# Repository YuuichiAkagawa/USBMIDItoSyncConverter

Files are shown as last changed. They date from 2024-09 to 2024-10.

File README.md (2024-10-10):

# USB MIDI to Sync Converter
Converts USB MIDI clock messages to sync signals.

[日本語版](README-ja.md)

## How to build
### Target microcontroller
- Seeed XIAO RP2040

### Build
This project uses Arduino IDE2 and requires the following libraries:
- board: [Arduino-pico](https://github.com/earlephilhower/arduino-pico) 4.1.1
- library: [Arduino MIDI Library](https://github.com/FortySevenEffects/arduino_midi_library) 5.0.2

Build setting:
- Tools->Board:->Raspberry Pi Pico/RP2040->Seed XIAO RP2040
- Tools->USB Stack:->Adafruilt TinyUSB

## Schematic
Complete schematic created in [KiCad](./hardware/KiCad/USBMIDItoSYNC_Converter/).

Minimum configuration with sync signal output terminal only
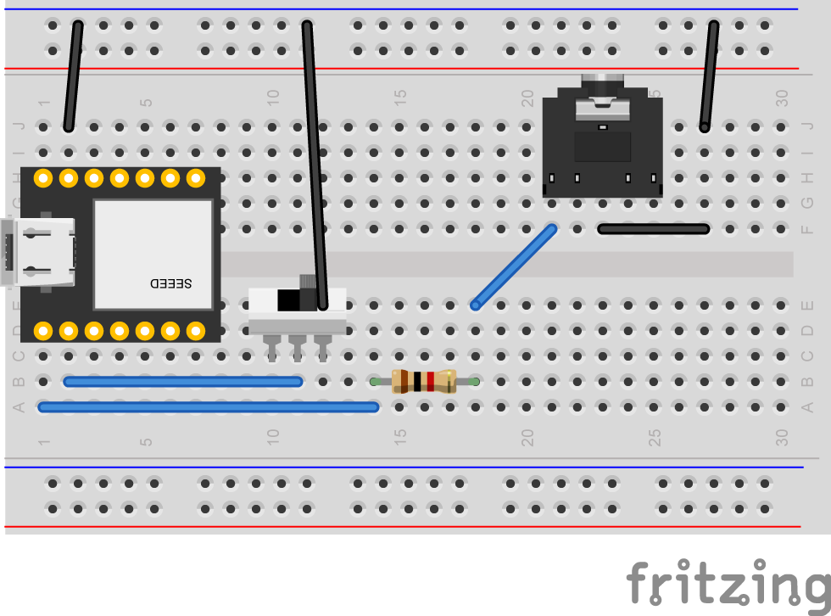
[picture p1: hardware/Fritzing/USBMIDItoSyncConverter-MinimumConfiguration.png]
Fritzing


## Usage
Connects to the sending MIDI device with a USB cable and to the receiving device with a 3.5 mm stereo cable.  
The run mode switch can be used to select the action to be taken when a MIDI START/STOP message is received.

### Run mode switch
The D1 pin is assigned to mode switch. D1 is pulled up and goes High when open.

|D1 |behaviour|
|----|---|
|Low |Sends out or stops the sync signal in conjunction with MIDI Start and Stop messages.|
|High|Free run. When MIDI Clock is received, the Sync signal is sent regardless of the playback status of the MIDI device.|

### DIN SYNC (experimental)
The DIN SYNC Start/Stop signal is output to the D2 pin.
D2 pin is assigned to 'DIN S' on the DIP switch and is connected to the RING of the Sync terminal.

### TRS MIDI In/Out (TypeA)
Transfers MIDI messages between USB MIDI and TRS MIDI.  
Note:
- SysEx is not supported.
- The clock input from TRS MIDI IN cannot be converted to a Sync signal.
  
### Setting switch
The setting switches can be used to set PPQ values and MIDI filter settings.  

|pin|name | setting |
|---|-----|---|
|D5 |MODE0|Type setting<br>L:PPQ values are changed using Setting switch. The value stored in the EEPROM is ignored.<br>H:PPQ values are changed using SysEx messages. Settings are saved in EEPROM.
|D4 |MODE1|MODE0=L : PPQ selecter<br>MODE0=H : MIDI FilterSelector
|D3 |MODE2|MODE0=L : PPQ selecter<br>MODE0=H : MIDI FilterSelector

#### MODE0=0 PPQ selector
|MODE1 |MODE2 | PPQ |
|---|---|---|
|H(Off)|H(Off)|1 |
|H(Off)|L(On) |2 |
|L(On) |H(Off)|4 |
|L(On) |L(On) |24 |

#### MODE0=1 MIDI Filter
|MODE1 |MODE2 | Filter |
|---|---|---|
|H(Off)|H(Off)|All messages are forwarded from USB to TRS MIDI Out |
|H(Off)|L(On) |Only Clock, Start, Stop, Continue are fowarded. |
|L(On) |H(Off)|Foward only clocks |
|L(On) |L(On) |N/A (Reserved) |

## About the pulse width of the sync signal
In this project, the pulse width of the sync signal is set to 5 ms.  
The reason for this is that the KORG specification is 15 ms, but many other companies' devices use 5 ms.  
If you want to change this, modify the definition of ```DEFAULT_SPW``` to ```SPW_15MS``` and rebuild.

## Change the PPQ via SysEx message
The PPQ values can be changed using SysEx messages.  
You can specify a value between 1 and 24, but it will not work correctly unless it is a divisor of 24.  
The PPQ value is stored in the EEPROM at location 0x00.

|Byte[Hex] | Description |
|:---:|---|
|F0 | Exclusive Status |
|7E | non realtime Universal System Exclusive Message |
|49 | Device ID |
|0B | File Reference Message |
|02 | Change (Select or Reselect) |
|nn | PPQ : 1,2,3,4,6,8,0Ch(12),18h(24) |
|F7 | End Of Exclusive |

## Change the Sync signal pulse width via SysEx message
The Sync signal pulse width can be changed using a SysEx message.  
It can be set to 5ms or 15ms.  
The Sync signal pulse width value is stored in the EEPROM at location 0x01.

|Byte[Hex] | Description |
|:---:|---|
|F0 | Exclusive Status |
|7E | non realtime Universal System Exclusive Message |
|49 | Device ID |
|0B | File Reference Message |
|02 | Change (Select or Reselect) |
|nn | Pulse Width 5ms:3Fh(63), 15ms:5Fh(95), Reserved:7Fh(127)|
|F7 | End Of Exclusive |

SysEx files are stored in assets/sysex. Use as needed.

Note: The SysEx message does not define a dedicated one, but rather diverts the universal system-exclusive File Reference Message.

## License
USB MIDI to Sync Converter is open source and licensed under the [GPL3](/LICENSE) License.

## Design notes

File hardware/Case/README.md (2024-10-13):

# Case
You can print the case on your 3D printer.  
The model for this case was created in FreeCAD.

## BOM
- Insert nut : M2 x 3mm L x 4mm
- Screw : M2x6

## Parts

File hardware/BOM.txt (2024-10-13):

 # |  package |  parts    |
---+----------+-----------+--------------------------------------------------
U1 |          |XIAO RP2040|Seeed XIAO RP2040 board
U2 |SO6       |TLP2368    |Photo coupler (open collector output)
U3 |SOT3-5    |SN74LV1T34 |Single Power Supply BUFFER Logic Level Shifter
R1 |1608(0603)|220Ω      |Register
R2 |1608(0603)|220Ω      |Register
R3 |1608(0603)|220Ω      |Register
R4 |1608(0603)|1kΩ       |Register
R5 |1608(0603)|1kΩ       |Register
R6 |1608(0603)|1kΩ       |Register
C1 |1608(0603)|0.1uF      |Ceramic capacitor
D1 |SOD123    |1N4148W    |Switching Diode
D2 |SOD523    |BAT43XV2   |Shotkey Diode 30V200mA
D3 |SOD523    |BAT43XV2   |Shotkey Diode 30V200mA
D4 |SOD523    |BAT43XV2   |Shotkey Diode 30V200mA
D5 |SOD523    |BAT43XV2   |Shotkey Diode 30V200mA
J1 |          |MJ8435     |3.5mm Stereo mini jack
J2 |          |MJ8435     |3.5mm Stereo mini jack
J3 |          |MJ8435     |3.5mm Stereo mini jack
SW1|          |3P SW      |Slide Switch 1P2T Right Angle
SW2|SO8       |KHS42E     |DIP Switch 4P SMT
---+----------+-----------+--------------------------------------------------

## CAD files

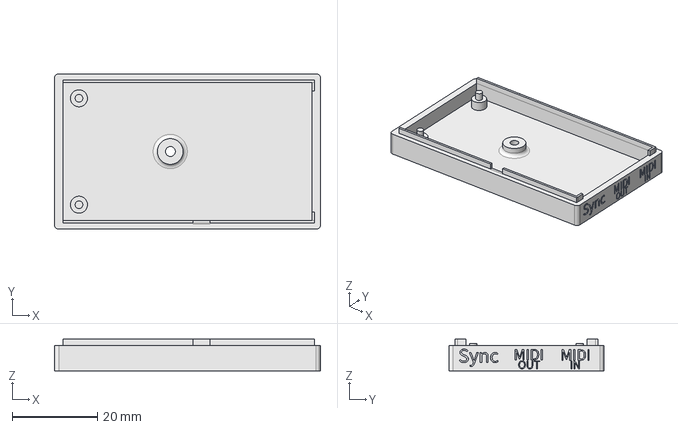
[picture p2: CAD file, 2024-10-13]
hardware/Case/UM2S-case-bottom.FCStd
62.5 x 36.5 x 7.50 mm

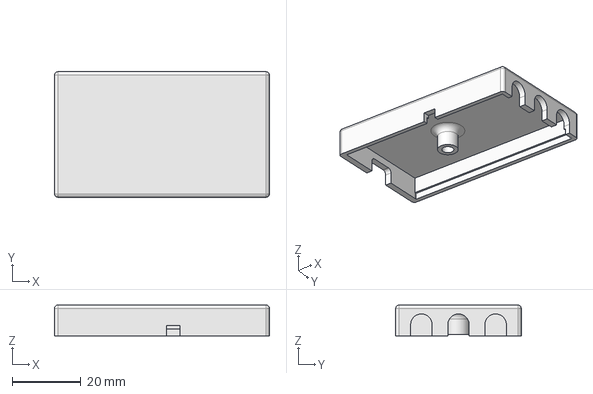
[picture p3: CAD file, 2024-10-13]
hardware/Case/UM2S-case-top.FCStd
62.5 x 36.5 x 9.00 mm

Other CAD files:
hardware/Case/UM2S-case-bottom.stl
hardware/Case/UM2S-case-top.stl

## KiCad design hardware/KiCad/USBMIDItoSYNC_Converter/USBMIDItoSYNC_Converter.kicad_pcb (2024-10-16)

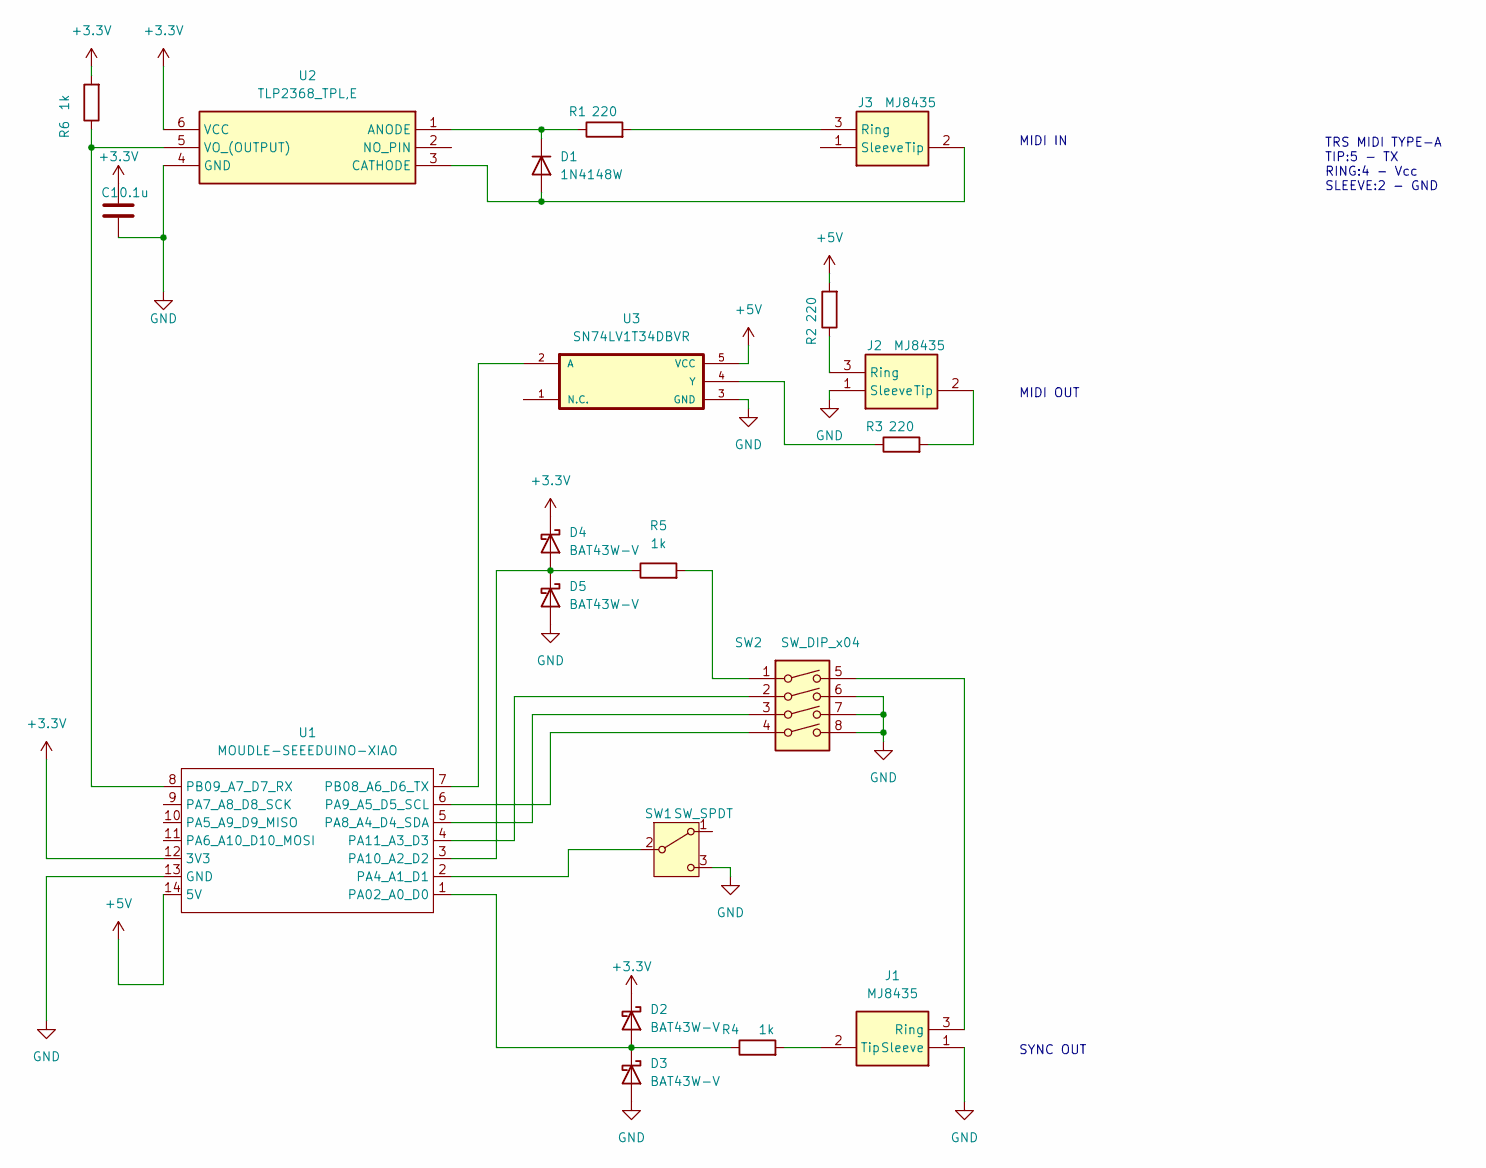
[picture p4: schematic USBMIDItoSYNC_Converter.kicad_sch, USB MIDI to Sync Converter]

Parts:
C1: 0.1u; C_0603_1608Metric
D1: 1N4148W; D_SOD-123
D2, D3, D4, D5: BAT43W-V; D_SOD-523
J1, J2, J3: MJ8435; Manufacturer_Part_Number MJ8435
R1, R2, R3: 220; R_0603_1608Metric
R4, R5, R6: 1k; R_0603_1608Metric
SW1: SW_SPDT; PinHeader_1x03_P2.54mm_Vertical
SW2: SW_DIP_x04; KHS42E
U1: MOUDLE-SEEEDUINO-XIAO; MOUDLE14P-XIAO-SMD-2.54-21X17.8MM
U2: TLP2368_TPL,E; SOIC127P700X230-6N; Manufacturer_Part_Number TLP2368(TPL,E; Mouser Part Number 757-TLP2368TPLE
U3: SN74LV1T34DBVR; SOT95P280X145-5N

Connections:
+3.3V: C1.1, D2.1 (K), D4.1 (K), R6.2, U1.12 (3V3), U2.6 (VCC)
+5V: R2.2, U1.14 (5V), U3.5 (VCC)
GND: C1.2, D3.2 (A), D5.2 (A), J1.1 (Sleeve), J2.1 (Sleeve), SW1.3 (C), SW2.6, SW2.7, SW2.8, U1.13 (GND), U2.4 (GND), U3.3 (GND)
unnamed: D1.2 (A), J3.2 (Tip), U2.3 (CATHODE)
unnamed: D1.1 (K), R1.1, U2.1 (ANODE)
unnamed: D2.2 (A), D3.1 (K), R4.1, U1.1 (PA02_A0_D0)
unnamed: D4.2 (A), D5.1 (K), R5.1, U1.3 (PA10_A2_D2)
unnamed: J1.3 (Ring), SW2.5
unnamed: J1.2 (Tip), R4.2
unnamed: J2.3 (Ring), R2.1
unnamed: J2.2 (Tip), R3.2
unnamed: J3.3 (Ring), R1.2
unnamed: R5.2, SW2.1
unnamed: SW1.2 (B), U1.2 (PA4_A1_D1)
unnamed: SW2.3, U1.5 (PA8_A4_D4_SDA)
unnamed: SW2.4, U1.6 (PA9_A5_D5_SCL)
unnamed: SW2.2, U1.4 (PA11_A3_D3)
unnamed: U1.7 (PB08_A6_D6_TX), U3.2 (A)
unnamed: R6.1, U1.8 (PB09_A7_D7_RX), U2.5 (VO_(OUTPUT))
unnamed: R3.1, U3.4 (Y)

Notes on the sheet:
MIDI IN
TRS MIDI TYPE-A TIP:5 - TX RING:4 - Vcc SLEEVE:2 - GND
SYNC OUT
MIDI OUT

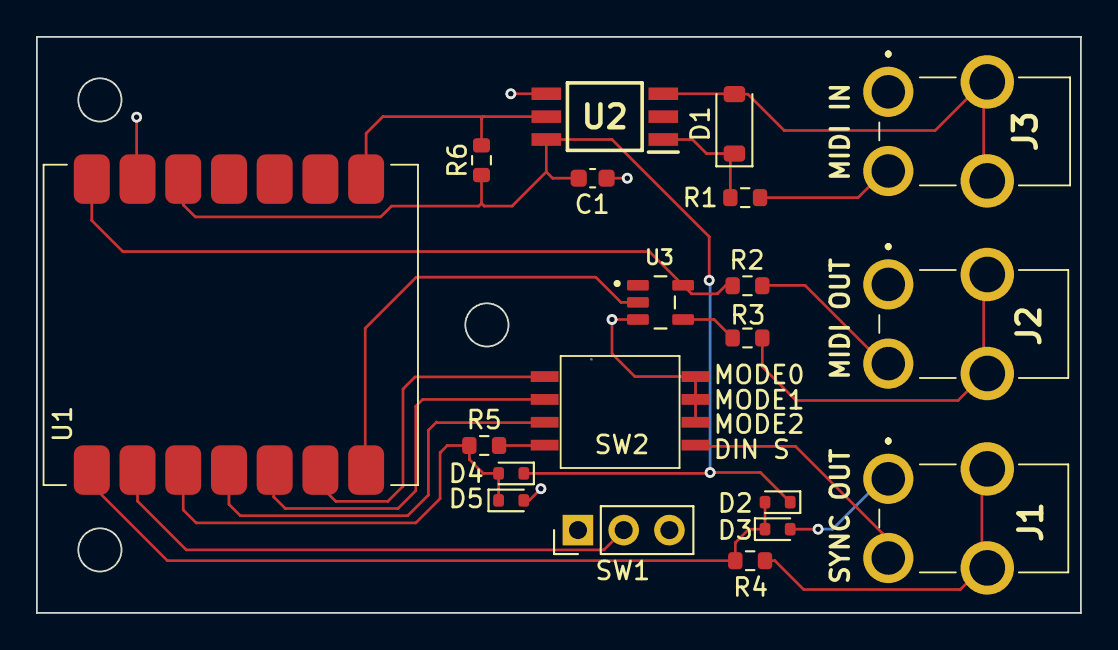
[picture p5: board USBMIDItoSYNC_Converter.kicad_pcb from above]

Board: 2 copper layers, 58.0 x 32.0 mm, 20 parts (0 on the bottom side), 20 nets.

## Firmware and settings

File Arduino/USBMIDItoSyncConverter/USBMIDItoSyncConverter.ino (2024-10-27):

/*
 * USB MIDI to Sync Converter for XIAO RP2040
 * Copyright (C) 2024 Yuuichi Akagawa
 *
 * This program is free software: you can redistribute it and/or modify it under the terms of 
 * the GNU General Public License as published by the Free Software Foundation, either version 3 
 * of the License, or any later version.
 * This program is distributed in the hope that it will be useful, but WITHOUT ANY WARRANTY; 
 * without even the implied warranty of MERCHANTABILITY or FITNESS FOR A PARTICULAR PURPOSE. 
 * See the GNU General Public License for more details.
 * You should have received a copy of the GNU General Public License along with this program. 
 * If not, see <https://www.gnu.org/licenses/>. 
 *
*/

#include <Arduino.h>
#include <Adafruit_TinyUSB.h>
#include <MIDI.h>
#include <EEPROM.h>

#define DEBUG
/* On-board LED definitions */
#define USER_LED_R 17  //RX_LED
#define USER_LED_G 16  //TX_LED
#define USER_LED_B 25

/* Pin definitions */
#define SYNCPIN D0
#define MODEPIN D1
#define DINSYNCRUNPIN D2
#define MODE0PIN D5
#define MODE1PIN D4
#define MODE2PIN D3
#define MODE0BIT 2
#define MODE1BIT 1
#define MODE2BIT 0

/* PPQ (default: 2PPQ)*/
#define CLOCK_BASE (24)
#define DEFAULT_PPQN (2)

/* Sync Pulse Width (SPW) */
#define SPW_5MS (1)
#define SPW_15MS (2)
#define SPW_RESERVED (3)
#define DEFAULT_SPW SPW_5MS

/* EEPROM address*/
#define EEPROM_ADDRESS_PPQN 0x00
#define EEPROM_ADDRESS_SPW 0x01

/* MIDI filter */
#define MIDI_FILTER_NONE (3)
#define MIDI_FILTER_TRANSPORT (2)
#define MIDI_FILTER_CLOCKONLY (1)

/* MIDI device ID for SysEx */
#define SYSEX_DEVICE_ID (0x49)

//Global valiables
uint32_t g_ppqn = DEFAULT_PPQN;  // current PPQN
uint32_t g_clock_period;         // Period of the MIDI Clock that fires the Sync signal
int32_t g_spw = -5;              // current Sync pluse width
uint32_t g_count_clock = 0;      // Number of MIDI Clocks received
bool g_is_start = false;         // Is MIDI Start received
uint32_t g_midi_filter = MIDI_FILTER_NONE;
uint32_t g_dipsw_mode_value = 0;

//timer
static repeating_timer_t timer;

// USB MIDI object
Adafruit_USBD_MIDI usb_midi;

// Create a new instance of the Arduino MIDI Library, and attach usb_midi as the transport.
MIDI_CREATE_INSTANCE(Adafruit_USBD_MIDI, usb_midi, USBMIDI);
// Create a new instance of the Arduino MIDI Library, and attach Serial1 as the transport.
MIDI_CREATE_INSTANCE(HardwareSerial, Serial1, MIDI);

bool timer_callback(repeating_timer_t *rt);
void startSync(void);
void handleClock(void);
void handleStart(void);
void handleStop(void);
void handleContinue(void);
void handleSysEx(byte *array, unsigned size);
uint8_t setPPQ(uint8_t c, uint8_t ppqn);
void setSPW(uint8_t c);
uint32_t getModeValue(void);
void applyModeValue(uint32_t sw);
bool isFilterd(uint32_t sw, byte type);

// Timer handler (one shot)
bool __not_in_flash_func(timer_callback)(repeating_timer_t *rt) {
  digitalWrite(SYNCPIN, LOW);
#ifdef DEBUG
  digitalWrite(LED_BUILTIN, HIGH);
#endif
  return false;
}

/**
 * Start Sync signal
 */
void __not_in_flash_func(startSync)() {
  g_count_clock = 0;
  digitalWrite(SYNCPIN, HIGH);  // Rise SYNC pin
#ifdef DEBUG
  digitalWrite(LED_BUILTIN, LOW);
#endif
  add_repeating_timer_ms(g_spw, &timer_callback, NULL, &timer);  // Start Timer
}

/**
 * MIDI message handlers
 */

// MIDI Clock
void __not_in_flash_func(handleClock)() {
  if (digitalRead(MODEPIN) == LOW) {
    if (g_is_start == false) {
      return;
    }
  }
  /* Count the number of timing clocks */
  g_count_clock++;
  if (g_count_clock >= g_clock_period) {
    startSync();
  }
}

// MIDI Start
void __not_in_flash_func(handleStart)() {
  g_is_start = true;
  g_count_clock = g_clock_period - 1;
  //for DIN SYNC
  digitalWrite(DINSYNCRUNPIN, HIGH);
}

// MIDI Stop
void __not_in_flash_func(handleStop)() {
  g_is_start = false;
  //for DIN SYNC
  digitalWrite(DINSYNCRUNPIN, LOW);
}

// MIDI Continue
void __not_in_flash_func(handleContinue)() {
  g_is_start = true;
  //for DIN SYNC
  digitalWrite(DINSYNCRUNPIN, HIGH);
}

// MIDI System exclusive
void __not_in_flash_func(handleSysEx)(byte *array, unsigned size) {
  /* Processing SysEx                                     */
  /*   Acceptable Messages                                */
  /*     device ID:49                                     */
  /*      F0 7E 49 0B 02 nn F7   : Change PPQN/SPW        */
  /*         PPQN nn = 0x01,0x02,0x03,0x04,0x08,0x0c,0x18 */
  /*         SPW  nn = 0x3F:5ms, 0x5F:15ms, 0x7F:Reserved */
  if (array[0] != 0xF0) return;             // SysEx start
  if (array[1] != 0x7e) return;             // non realtime universal system exclusive message
  if (array[2] != SYSEX_DEVICE_ID) return;  // device ID
  if (array[3] != 0x0B) return;             // File Reference Message
  if (array[4] != 0x02) return;             // change
  if (array[6] != 0xf7) return;             // SysEx end
  byte c = array[5];
  //Change PPQN
  g_ppqn = setPPQ(c, g_ppqn);
  g_clock_period = (CLOCK_BASE / g_ppqn);
  //Change SPW
  setSPW(c);
}

/**
 * Set and Save PPQN
 * c: PPQN : 1 to 24
 *   bit|7|6|5|4|3|2|1|0|
 *      |0|0|0|PPQN 0-24|
 */
uint8_t setPPQ(uint8_t c, uint8_t ppqn) {
  uint8_t newPpqn = ppqn;

  // bit 6,5
  // 00 : PPQN mode, 01-11: SPW mode
  if ((c & 0x60) != 0) {
    return newPpqn;
  }

  //Extracting PPQN value
  c = c & 0x1f;
  if (0 < c && c <= 24) {  // Valid range is 1 to 24
    newPpqn = c;
    EEPROM.write(EEPROM_ADDRESS_PPQN, newPpqn);
    EEPROM.commit();
  }
  return newPpqn;
}

/**
 * Set and Save clock pluse width
 * c: SPW | bit 6,5 = 00: PPQN mode, 01: SPW 5ms, 10: SPW 15ms, 11: Reserved
 *   bit|7|6|5|4|3|2|1|0|
 *      |0|X|X|1|1|1|1|1|
 */
void setSPW(uint8_t c) {
  // Bits 0 through 4 must all be 1
  if ((c & 0x1f) != 0x1f) {
    return;
  }

  //Extracting SPW value
  uint8_t new_spw = (c >> 5) & 3;
  if (new_spw == 0) {
    return;
  }
  //Save SPW value
  EEPROM.write(EEPROM_ADDRESS_SPW, new_spw);
  EEPROM.commit();
  //set SPW
  switch (new_spw) {
    case SPW_5MS:
      g_spw = -5;
      break;
    case SPW_15MS:
      g_spw = -15;
      break;
    default:
      g_spw = -5;
      break;
  }
}
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

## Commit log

2024-09-23 First working project
    [USBMIDItoSYNC_Converter.kicad_pcb, USBMIDItoSYNC_Converter.kicad_sch, USBMIDItoSyncConverter-MinimumConfiguration.fzz]
2024-09-24 fix the PPQ value with DIP switches
    [USBMIDItoSyncConverter.ino]
2024-10-13 Add case 3D model data
    [UM2S-case-bottom.FCStd, UM2S-case-bottom.stl, UM2S-case-top.FCStd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]
2024-10-13 fix schematic : protection circuit
    [USBMIDItoSYNC_Converter.kicad_pcb, USBMIDItoSYNC_Converter.kicad_sch]
2024-10-16 fix schematic : add OSHW logo
    [USBMIDItoSYNC_Converter.kicad_pcb]
2024-10-27 Change: USB VID and PID
